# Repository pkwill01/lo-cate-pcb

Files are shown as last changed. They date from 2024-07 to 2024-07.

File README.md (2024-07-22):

# lo-cate
A PCB and firmware project to create a simple LoRa capable device with an intergrated IMU. 
## PCB
The PCB was designed to be simple, power over USB and be manufactorable using basic electrical tooling.

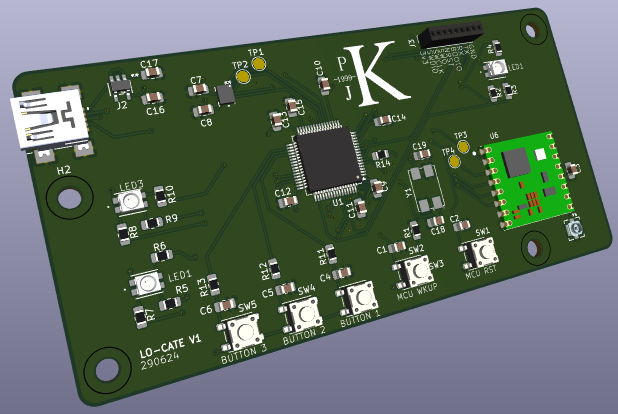
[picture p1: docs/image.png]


### Overview
 - **LoRa**; Connected to the micro via SPI, the antenna connection is terminated to a U.FL SMD connector w/ track impedance matched to 50&Omega;
 - **IMU**; Connected to micro via SPI 
 - **Microcontroller**; STM32F401RET7 w/ an 8MHz external oscillator to allow USB OTG capabilities. 
 - **USB**; Mini B for communicating between the STM and external PC, 5v in fed into a 3.3v linear reg for use by all IC's
 - **LED's**; 3 RGB LED's connected to the micros power outputs for baic HMI
 - **Buttons**; Debounced using RC filter and connected to interrupt capable pins on the micro, MCU WKUP is connected to the micros sleep wakeup pin

### PCB TODO 
 - [] Change the Programming header for the STM32 from the 1.27mm pins
 - [] Fix the oscillator circuit to fit into the STM32 design guidlines C19 & C18 should be calculated via C_L = 2*(C_Load - C_Stray) also R14 can be removed from circuit 
 - [] Fix the LED footprints 

## Firmware

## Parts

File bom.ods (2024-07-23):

Ord | More? | Component | Spec | $ | Qty | Total $ | Ord | Rec | Reference | Value | Footprint | Qty | $ | Total $
 | M | LoRa Module (https://www.digikey.com.au/en/products/detail/rf-solutions/RFM95W-868S2/5051755?_gl=1*dk7re0*_up*MQ..) | RFM95W-868S2 | 22.68 | 1 | 22.68 |  | N | C1,C2,C3,C4,C5,C6,C7,C8,C9,C10,C11,C12,C13,C14,C16 | 0.1uF (https://www.digikey.com.au/en/products/detail/yageo/CC0805KRX7R9BB104/302874) | C_0805_2012 | 15 | 0.16 | 2.4
Y | y | STM32 (https://www.digikey.com.au/en/products/detail/stmicroelectronics/STM32F401RET7/6621729?Enterprise=44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) | STM32F401RET7 | 8.59 | 1 | 8.59 |  | N | C15 | 4.7uF (https://www.digikey.com.au/en/products/detail/samsung-electro-mechanics/CL21A475KAQNNNE/3886902) | C_0805_2013 | 1 | 0.16 | 0.16
Y | Y 1 | IMU (https://www.digikey.com.au/en/products/detail/bosch-sensortec/BMI323/16719593) | BMI323 | 7.1 | 1 | 7.1 |  | N | C17 | 0.47uF (https://www.digikey.com.au/en/products/detail/murata-electronics/GRM21BR71H474KA88L/702592) | C_0805_2014 | 1 | 0.36 | 0.36
Y | Y 3 | Buttons (https://www.digikey.com.au/en/products/detail/c-k/PTS-647-SN50-SMTR2-LFS/9649857) | PTS 647 SN50 SMTR2 LFS | 0.28 | 5 | 1.4 | Y | Y | C18,C19 | 12p (https://www.digikey.com.au/en/products/detail/yageo/CC0805JRNPO9BN120/302834) | C_0805_2015 | 2 | 0.16 | 0.32
Y | Y 3 | Led’s (https://www.digikey.com.au/en/products/detail/würth-elektronik/150141M173100/4489960) | 150141M173100 | 0.57 | 2 | 1.14 |  | N | R1 | 10k (https://www.digikey.com.au/en/products/detail/yageo/RC0805FR-0710KL/727535) | R_0805_2012 | 1 | 0.16 | 0.16
 | N | USB Mini B (https://www.digikey.com.au/en/products/detail/edac-inc/690-005-299-043/4312191) | 690-005-299-043 | 1.02 | 1 | 1.02 | Y | Y | R2,R3,R4,R5,R6,R7,R8,R9,R10 | 60Ω (https://www.digikey.com.au/en/products/detail/yageo/RC0805FR-0760R4L/728073) | R_0805_2013 | 9 | 0.16 | 1.44
 | N | Programming Header | Header Pins | 3 | 1 | 3 |  | N | R11,R12,R13 | 50k (https://www.digikey.com.au/en/products/detail/vishay-beyschlag-draloric-bc-components/MCU08050D5002BP100/8125783) | R_0805_2014 | 3 | 1.33 | 3.99
 | N | Linear Regulator (https://www.digikey.com.au/en/products/detail/stmicroelectronics/LDK320AM33R/6192795) | LDK320AM33R | 1.04 | 1 | 1.04 | Y | Y 4 | R14,R15 | 4.7K (https://www.digikey.com.au/en/products/detail/yageo/RC0805FR-0714K7L/727600) | R_0805_2015 | 2 | 0.28 | 0.56
 | N | Antenna (https://www.digikey.com.au/en/products/detail/molex/2067640100/9520958) | 2067640100 | 6.85 | 1 | 6.85
 | N | u.FL connector (https://www.digikey.com.au/en/products/detail/0734120114/WM3894CT-ND/2421931?curr=usd) | U.FL-R-SMT-1(10) | 1.51 | 1 | 1.51
Y | Y 1 | Oscillator (https://www.digikey.com.au/en/products/detail/LFXTAL026380/1923-LFXTAL026380CT-ND/8634020?curr=usd) | LFXTAL026380 | 1.51 | 1 | 1.51 |  |  |  |  |  |  |  | 9.39
 |  |  |  | 1.3 | 1 | 1.3
 |  |  |  |  |  | 0
 |  |  |  |  |  | 0
 |  |  |  |  |  | 0
 |  |  |  |  |  | 52.82

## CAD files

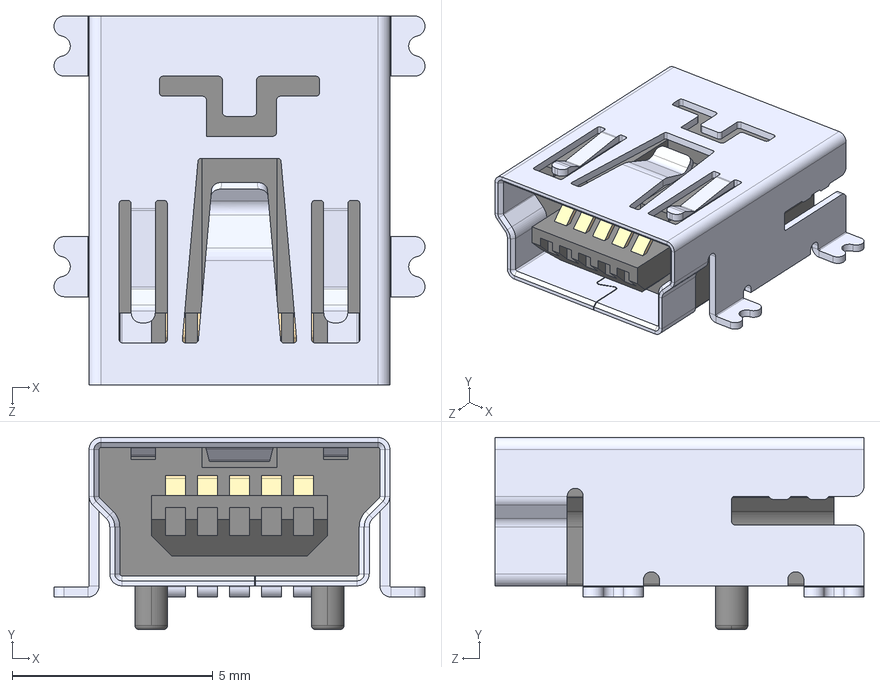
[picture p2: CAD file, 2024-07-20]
pcb/690-005-299-043.step
9.25 x 4.79 x 9.20 mm

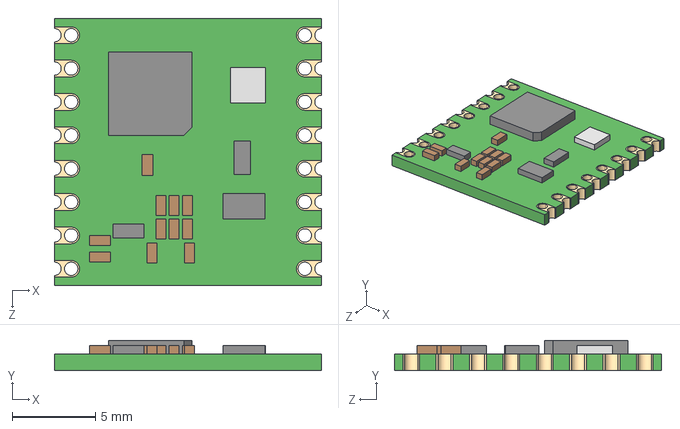
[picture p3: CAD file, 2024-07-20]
pcb/footprint_libs/step/RFM95W-868S2.step
16.0 x 1.80 x 16.0 mm

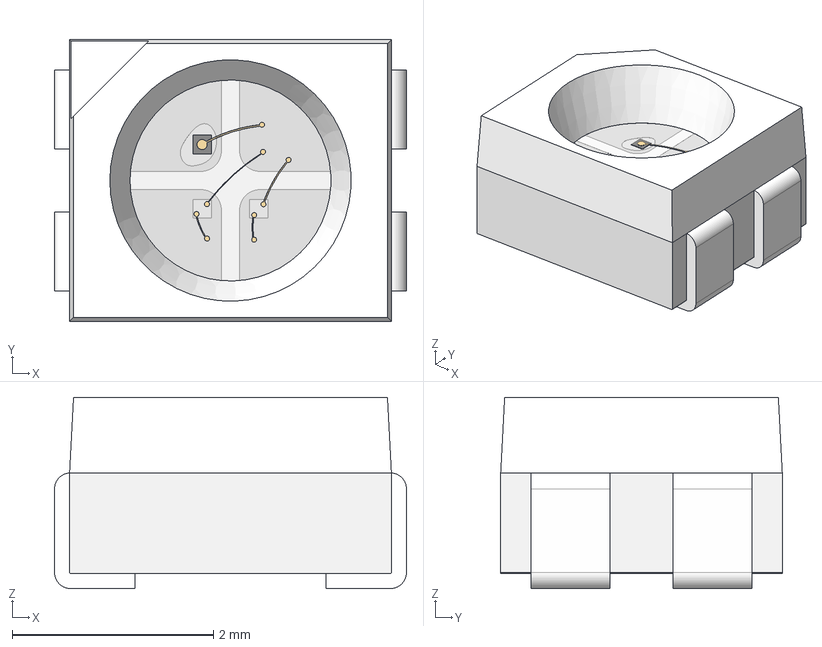
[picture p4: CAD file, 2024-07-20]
pcb/footprint_libs/step/WL-SFTW_3528_PLCC4.step
3.50 x 2.80 x 1.90 mm
cover
housing
base x 2

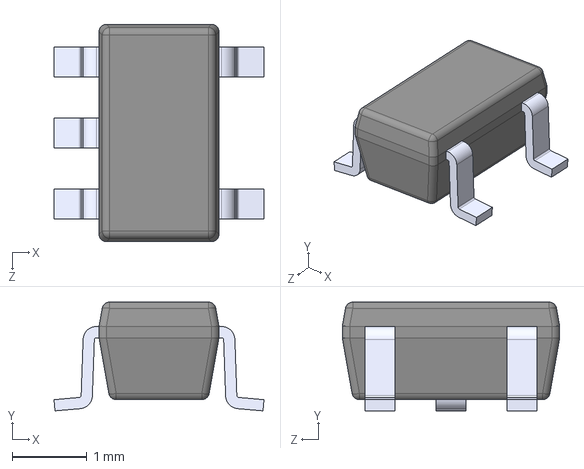
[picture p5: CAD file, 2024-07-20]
pcb/footprint_libs/step/LDK320AM33R.step
2.80 x 1.45 x 2.90 mm

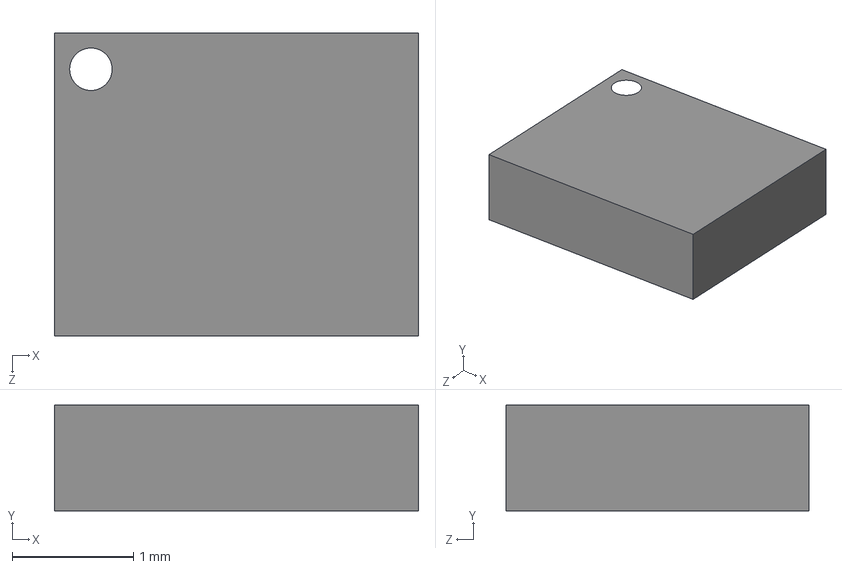
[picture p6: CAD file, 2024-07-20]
pcb/footprint_libs/step/BMI323.step
3.00 x 0.87 x 2.50 mm

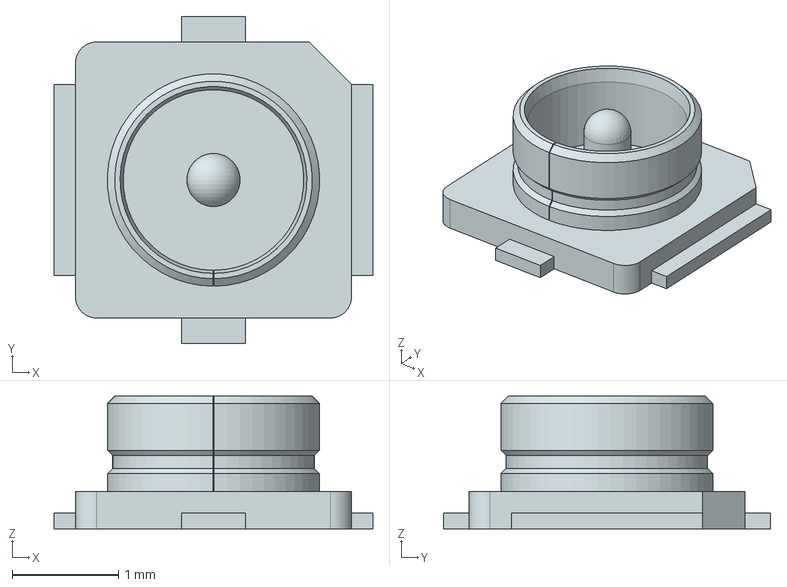
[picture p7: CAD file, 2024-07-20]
pcb/footprint_libs/step/734120114.stp
3.00 x 3.08 x 1.25 mm

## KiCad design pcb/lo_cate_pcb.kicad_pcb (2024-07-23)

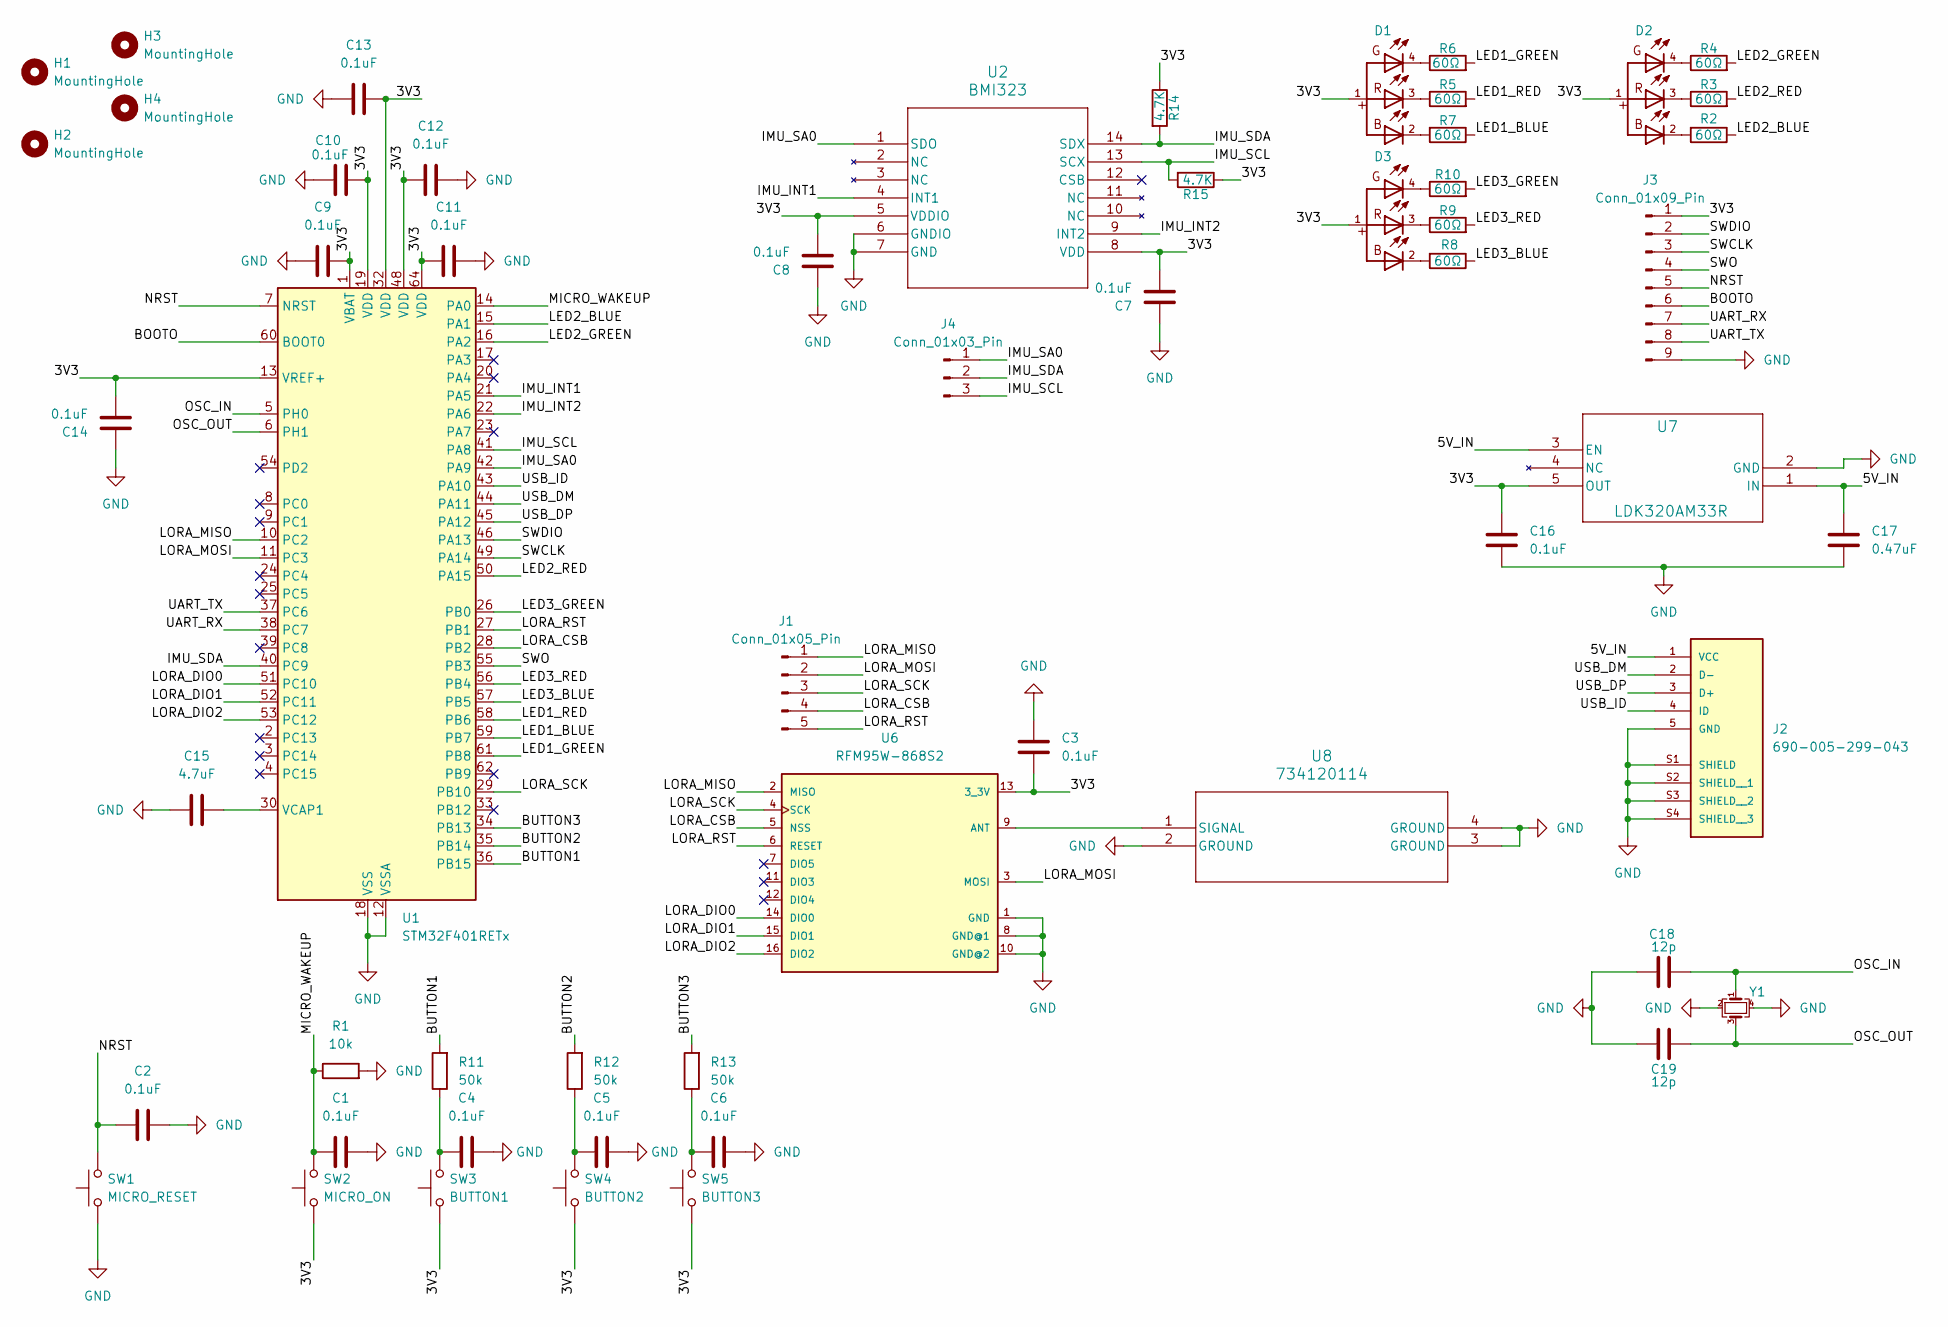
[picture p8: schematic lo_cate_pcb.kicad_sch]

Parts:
C1, C2, C3, C4, C5, C6, C7, C8, C9, C10, C11, C12, C13, C14, C16: 0.1uF; C_0805_2012Metric_Pad1.18x1.45mm_HandSolder
C15: 4.7uF; C_0805_2012Metric_Pad1.18x1.45mm_HandSolder
C17: 0.47uF; C_0805_2012Metric_Pad1.18x1.45mm_HandSolder
C18, C19: 12p; C_0805_2012Metric_Pad1.18x1.45mm_HandSolder
D1, D2, D3: WL-SFTW_3528_PLCC4
H1, H2, H3, H4: MountingHole; MountingHole_3.2mm_M3
J1: Conn_01x05_Pin; PinSocket_1x05_P2.54mm_Vertical
J2: 690-005-299-043; EDAC_690-005-299-043; PARTREV 11
J3: Conn_01x09_Pin; PinSocket_1x09_P2.54mm_Vertical
J4: Conn_01x03_Pin; PinSocket_1x03_P2.54mm_Vertical
R1: 10k; R_0805_2012Metric_Pad1.20x1.40mm_HandSolder
R2, R3, R4, R5, R6, R7, R8, R9, R10: 60Ω; R_0805_2012Metric_Pad1.20x1.40mm_HandSolder
R11, R12, R13: 50k; R_0805_2012Metric_Pad1.20x1.40mm_HandSolder
R14, R15: 4.7K; R_0805_2012Metric_Pad1.20x1.40mm_HandSolder
SW1: MICRO_RESET; SW_SPST_PTS647_Sx38
SW2: MICRO_ON; SW_SPST_PTS647_Sx38
SW3: BUTTON1; SW_SPST_PTS647_Sx38
SW4: BUTTON2; SW_SPST_PTS647_Sx38
SW5: BUTTON3; SW_SPST_PTS647_Sx38
U1: STM32F401RETx; LQFP-64_10x10mm_P0.5mm
U2: BMI323; BMI323_BOS-M
U6: RFM95W-868S2; XCVR_RFM95W-868S2
U7: LDK320AM33R; SOT23-5L_STM-M
U8: 734120114; 73412-0114_MOL
Y1: Crystal_GND24_Small; Crystal_SMD_7050-4Pin_7.0x5.0mm

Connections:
/3V3: C3.2, C7.2, C8.2, C9.1, C10.1, C11.2, C12.2, C13.2, C14.2, C16.1, D1.1, D2.1, D3.1, J3.1, R14.1, R15.1, SW2.1, SW3.1, SW4.1, SW5.1, U1.1 (VBAT), U1.13 (VREF+), U1.19 (VDD), U1.32 (VDD), U1.48 (VDD), U1.64 (VDD), U2.5 (VDDIO), U2.8 (VDD), U6.13 (3_3V), U7.5 (OUT)
/5V_IN: C17.1, J2.1 (VCC), U7.1 (IN), U7.3 (EN)
/BOOTO: J3.6, U1.60 (BOOT0)
/BUTTON1: R11.2, U1.36 (PB15)
/BUTTON2: R12.2, U1.35 (PB14)
/BUTTON3: R13.2, U1.34 (PB13)
/IMU_INT1: U1.21 (PA5), U2.4 (INT1)
/IMU_INT2: U1.22 (PA6), U2.9 (INT2)
/IMU_SA0: J4.1, U1.42 (PA9), U2.1 (SDO)
/IMU_SCL: J4.3, R15.2, U1.41 (PA8), U2.13 (SCX)
/IMU_SDA: J4.2, R14.2, U1.40 (PC9), U2.14 (SDX)
/LED1_BLUE: R7.1, U1.59 (PB7)
/LED1_GREEN: R6.2, U1.61 (PB8)
/LED1_RED: R5.2, U1.58 (PB6)
/LED2_BLUE: R2.1, U1.15 (PA1)
/LED2_GREEN: R4.2, U1.16 (PA2)
/LED2_RED: R3.2, U1.50 (PA15)
/LED3_BLUE: R8.1, U1.57 (PB5)
/LED3_GREEN: R10.2, U1.26 (PB0)
/LED3_RED: R9.2, U1.56 (PB4)
/LORA_CSB: J1.4, U1.28 (PB2), U6.5 (NSS)
/LORA_DIO0: U1.51 (PC10), U6.14 (DIO0)
/LORA_DIO1: U1.52 (PC11), U6.15 (DIO1)
/LORA_DIO2: U1.53 (PC12), U6.16 (DIO2)
/LORA_MISO: J1.1, U1.10 (PC2), U6.2 (MISO)
/LORA_MOSI: J1.2, U1.11 (PC3), U6.3 (MOSI)
/LORA_RST: J1.5, U1.27 (PB1), U6.6 (RESET)
/LORA_SCK: J1.3, U1.29 (PB10), U6.4 (SCK)
/MICRO_WAKEUP: C1.2, R1.1, SW2.2, U1.14 (PA0)
/NRST: C2.2, J3.5, SW1.2, U1.7 (NRST)
/OSC_IN: C18.1, U1.5 (PH0), Y1.1
/OSC_OUT: C19.1, U1.6 (PH1), Y1.3
/SWCLK: J3.3, U1.49 (PA14)
/SWDIO: J3.2, U1.46 (PA13)
/SWO: J3.4, U1.55 (PB3)
/UART_RX: J3.7, U1.38 (PC7)
/UART_TX: J3.8, U1.37 (PC6)
/USB_DM: J2.2 (D-), U1.44 (PA11)
/USB_DP: J2.3 (D+), U1.45 (PA12)
/USB_ID: J2.4 (ID), U1.43 (PA10)
GND: C1.1, C2.1, C3.1, C4.1, C5.1, C6.1, C7.1, C8.1, C9.2, C10.2, C11.1, C12.1, C13.1, C14.1, C15.2, C16.2, C17.2, C18.2, C19.2, J2.5 (GND), J2.S1 (SHIELD), J2.S2 (SHIELD__1), J2.S3 (SHIELD__2), J2.S4 (SHIELD__3), J3.9, R1.2, SW1.1, U1.12 (VSSA), U1.18 (VSS), U1.31 (VSS), U1.47 (VSS), U1.63 (VSS), U2.6 (GNDIO), U2.7 (GND), U6.1 (GND), U6.8 (GND@1), U6.10 (GND@2), U7.2 (GND), U8.2 (GROUND), U8.3 (GROUND), U8.4 (GROUND), Y1.2, Y1.4
unnamed: C4.2, R11.1, SW3.2
unnamed: C5.2, R12.1, SW4.2
unnamed: C6.2, R13.1, SW5.2
unnamed: D1.2, R7.2
unnamed: D1.3, R5.1
unnamed: D1.4, R6.1
unnamed: D2.2, R2.2
unnamed: D2.3, R3.1
unnamed: D2.4, R4.1
unnamed: D3.2, R8.2
unnamed: D3.3, R9.1
unnamed: D3.4, R10.1
unnamed: C15.1, U1.30 (VCAP1)
unnamed: U6.9 (ANT), U8.1 (SIGNAL)

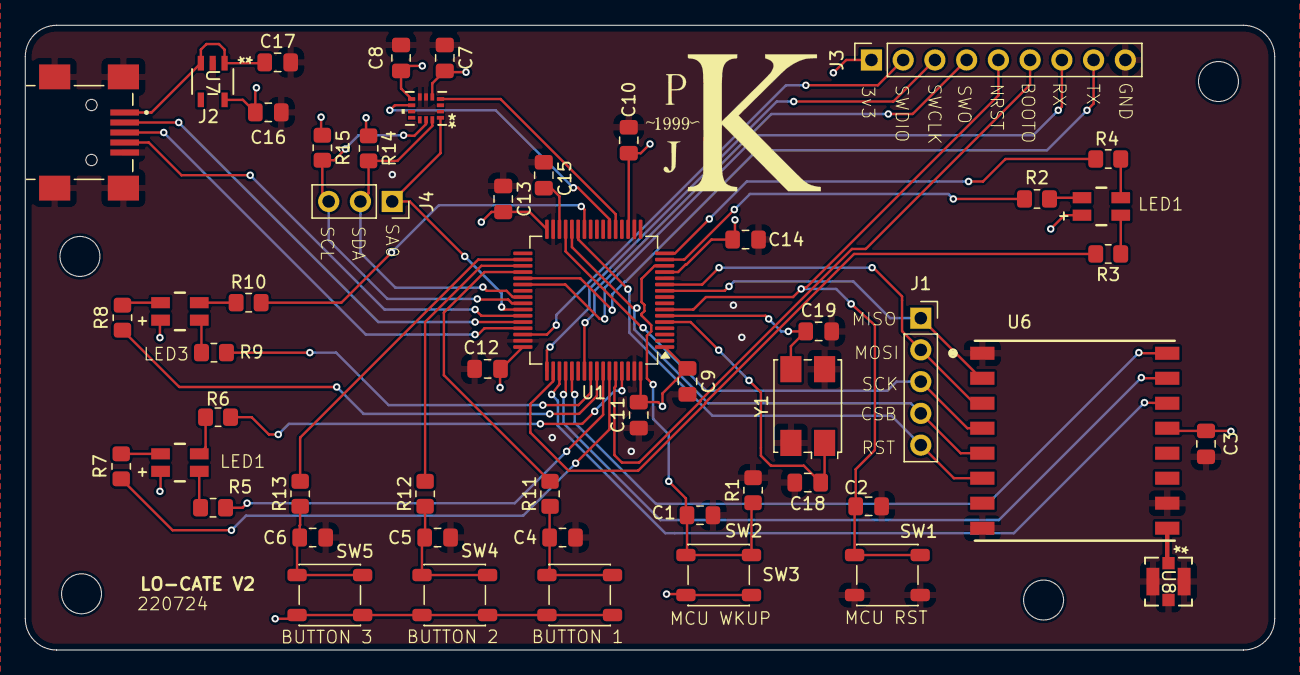
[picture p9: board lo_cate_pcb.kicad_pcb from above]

Board: 4 copper layers, 100.0 x 50.0 mm, 56 parts (0 on the bottom side), 55 nets.

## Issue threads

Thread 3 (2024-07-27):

Make Changes for PCB v3

pkwill01, 2024-07-27:

pkwill01, 2024-07-28:
- [ ] The PCB traces for the USB connection need to be routed like as a differential pair (because they are). [This](https://www.digikey.com.au/en/maker/projects/how-to-route-differential-pairs-in-kicad-for-usb/45b99011f5d34879ae1831dce1f13e93) demos how this can be done.

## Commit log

2024-07-20 Added the PCB files into the repo
    [690-005-299-043.step, 734120114.stp, BMI323.step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]
2024-07-22 Made changes the PCB to take it to version 2, bom just needs updating now
    [lo_cate_pcb.kicad_pcb, lo_cate_pcb.kicad_sch]
2024-07-23 BOM Updated
    [bom.ods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]
